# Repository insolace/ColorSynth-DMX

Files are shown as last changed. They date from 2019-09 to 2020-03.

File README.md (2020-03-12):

# ColorSynth-DMX<br>
163 DMX RGB pixels for a Burningman 2013 geodesic dome located at camp Morning Cookie<br>
Designed and assembled by Eric Bateman<br>
BMP to DMX mapping done in collaboration with Craig Dorety (http://craigdorety.com/)<br>

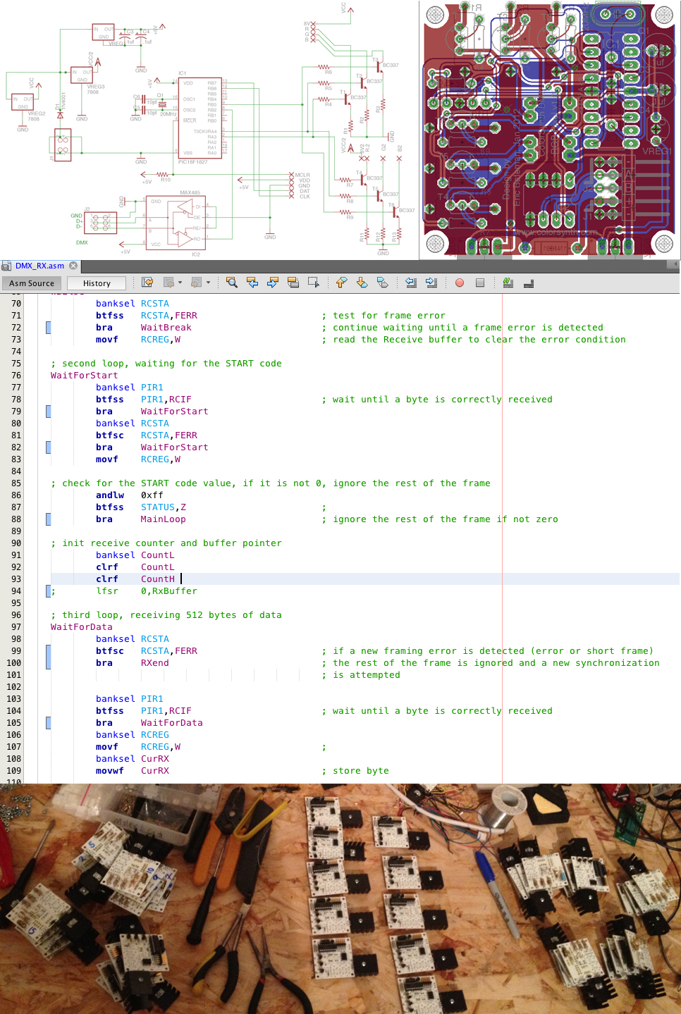
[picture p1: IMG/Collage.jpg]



ColorSynth DMX RGX pixels are three channel DMX fixtures.  Programmed in assembly, the channels are software defined.

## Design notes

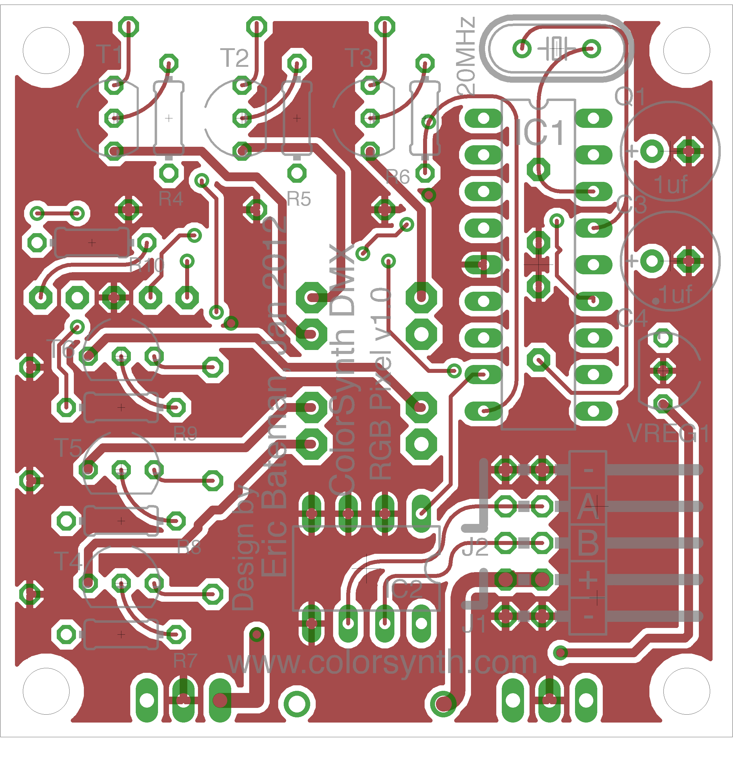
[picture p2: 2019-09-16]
PCB and Schematic/PCB export/DMX_RX_2RGB_TOP_BOTH.png

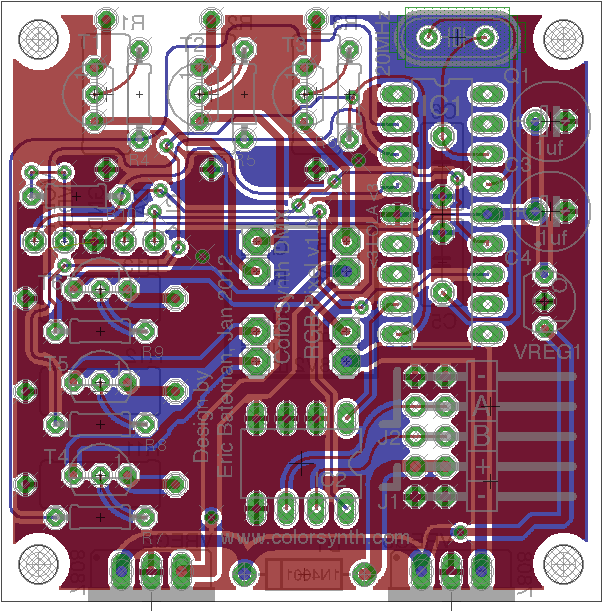
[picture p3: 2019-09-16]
PCB and Schematic/DMX RX PCB.png

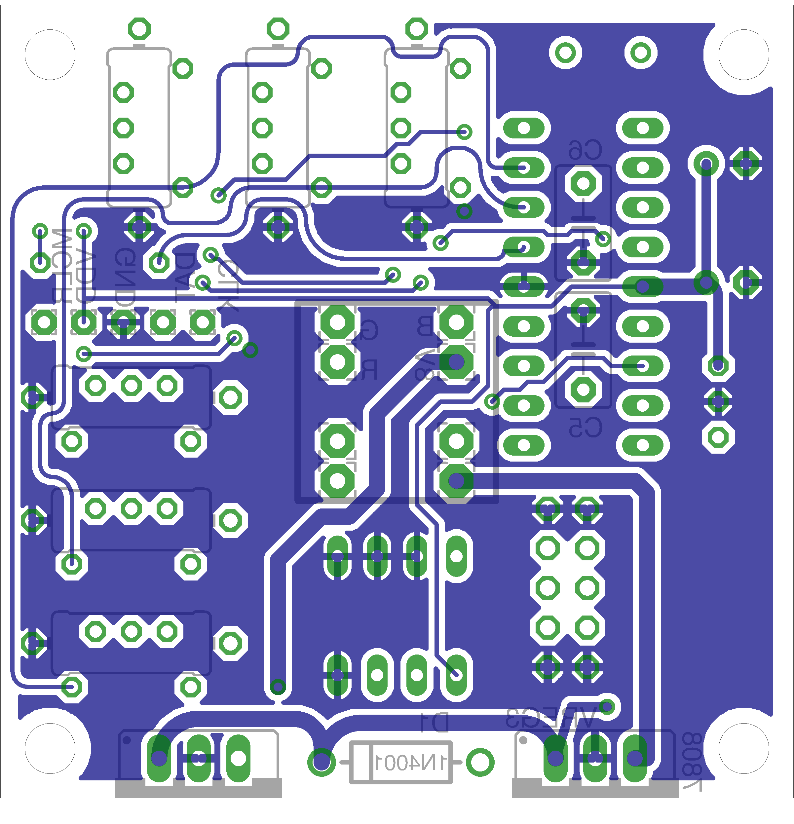
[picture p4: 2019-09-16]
PCB and Schematic/PCB export/DMX_RX_2RGB_BOT_BOTH.png

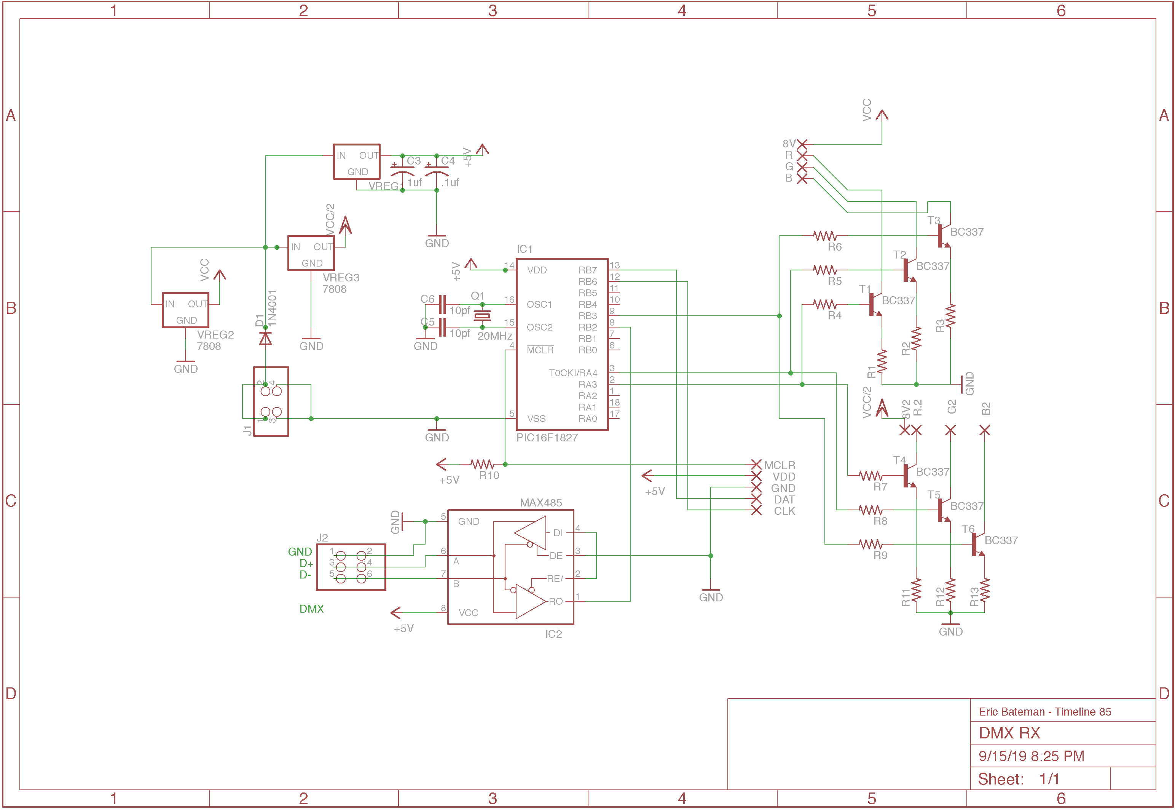
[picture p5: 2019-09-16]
PCB and Schematic/DMX RX Schematic.png

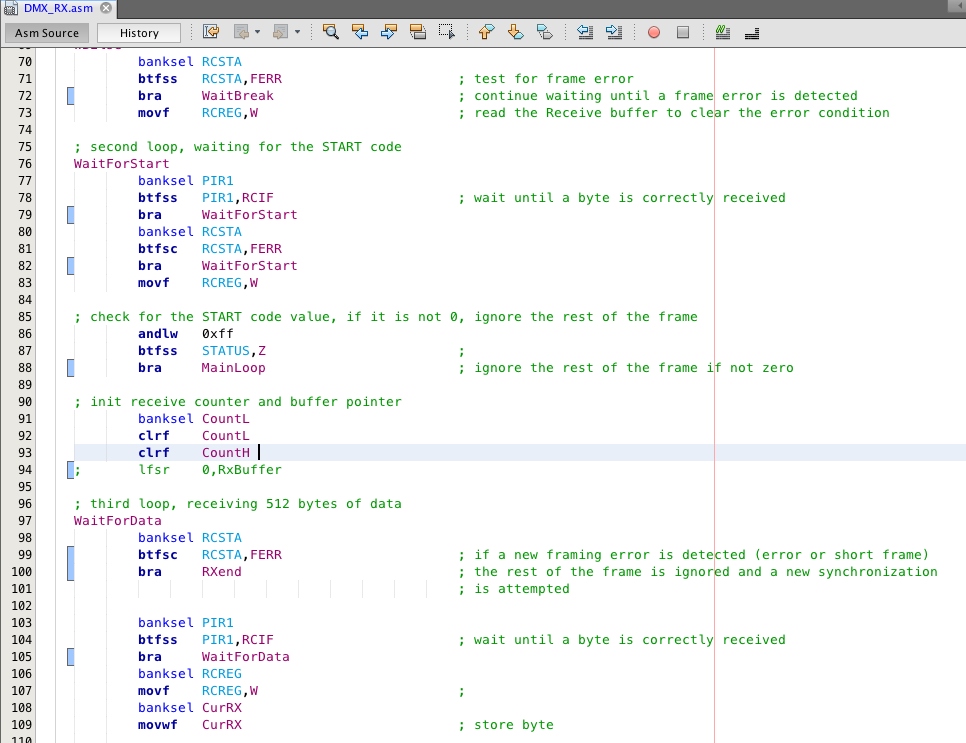
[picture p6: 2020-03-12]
IMG/DMX-ASM.png

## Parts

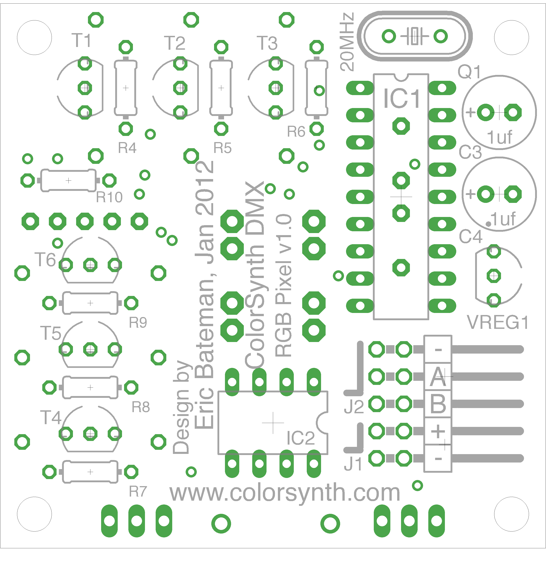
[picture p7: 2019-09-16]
PCB and Schematic/PCB export/DMX_RX_2RGB_TOP_PARTS.png

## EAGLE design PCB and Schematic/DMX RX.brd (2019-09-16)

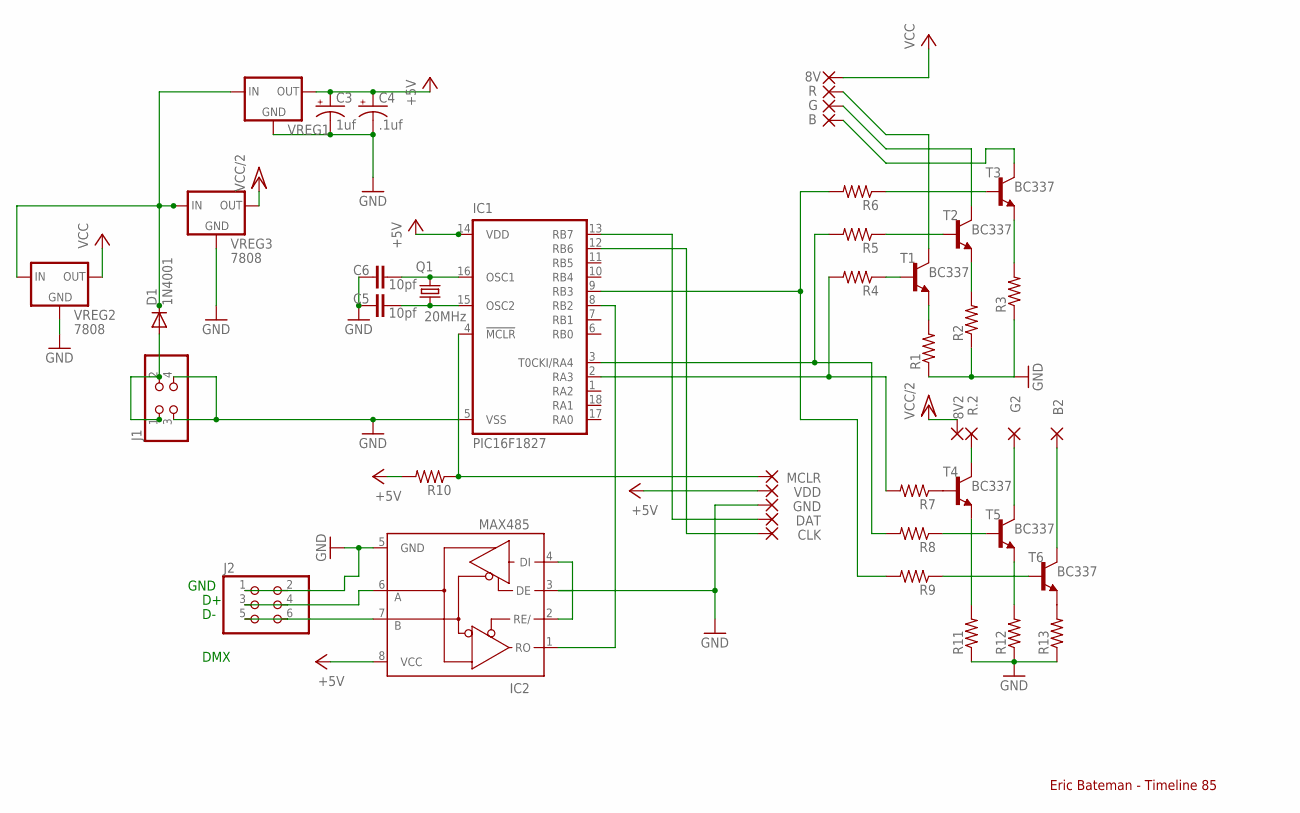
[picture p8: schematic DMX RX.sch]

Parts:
8V, 8V2: 2,15/1,0
B, B2: 2,15/1,0
C3: 1uf; E2,5-7
C4: .1uf; E2,5-7
C5, C6: 10pf; C5B3.5
CLK: 1,6/0,8
D1: 1N4001; DIODE-1N4001
DAT: 1,6/0,8
G, G2: 2,15/1,0
GND: 1,6/0,8
IC1: PIC16F1827; DIL18
IC2: MAX485; DIL08
J1: PINHD-2X2/90; 2X02/90
J2: PINHD-2X3/90; 2X03/90
MCLR: 1,6/0,8
Q1: 20MHz; HC49/S
R, R.2: 2,15/1,0
R1, R2, R3, R11, R12, R13: R-US_0411/12; 0411/12
R4, R5, R6, R7, R8, R9, R10: R-US_0204/7; 0204/7
T1, T2, T3, T4, T5, T6: BC337; TO92
VDD: 1,6/0,8
VREG1: 78LXX
VREG2, VREG3: 7808; 78XXS

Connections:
+5V: C3.+, C4.+, IC1.14 (VDD), IC2.8 (VCC), R10.2, VDD.1, VREG1.OUT
+12V: D1.C, VREG1.IN, VREG2.IN, VREG3.IN
A: IC2.6 (A), J2.3, J2.4
B: IC2.7 (B), J2.5, J2.6
CLK: CLK.1, IC1.12 (RB6)
DAT: DAT.1, IC1.13 (RB7)
DC-IN: D1.A, J1.1, J1.2
GND: C3.-, C4.-, C5.2, C6.2, GND.1, IC1.5 (VSS), IC2.2 (RE/), IC2.3 (DE), IC2.4 (DI), IC2.5 (GND), J1.3, J1.4, J2.1, J2.2, R1.1, R2.1, R3.1, R11.1, R12.1, R13.1, VREG1.GND, VREG2.GND, VREG3.GND
MCLR: IC1.4 (!MCLR), MCLR.1, R10.1
unnamed: R6.1, T3.2 (B)
unnamed: R3.2, T3.1 (E)
unnamed: R1.2, T1.1 (E)
unnamed: C6.1, IC1.16 (OSC1), Q1.1
unnamed: C5.1, IC1.15 (OSC2), Q1.2
unnamed: IC1.2 (RA3), R4.2, R7.2
unnamed: IC1.3 (T0CKI/RA4), R5.2, R8.2
unnamed: IC1.9 (RB3), R6.2, R9.2
unnamed: R5.1, T2.2 (B)
unnamed: R4.1, T1.2 (B)
unnamed: R.1, T1.3 (C)
unnamed: G.1, T2.3 (C)
unnamed: R2.2, T2.1 (E)
unnamed: R7.1, T4.2 (B)
unnamed: R13.2, T6.1 (E)
unnamed: R12.2, T5.1 (E)
unnamed: R11.2, T4.1 (E)
unnamed: R9.1, T6.2 (B)
unnamed: R8.1, T5.2 (B)
unnamed: G2.1, T5.3 (C)
unnamed: B2.1, T6.3 (C)
unnamed: R.2.1, T4.3 (C)
unnamed: B.1, T3.3 (C)
RX: IC1.8 (RB2), IC2.1 (RO)
VCC: 8V.1, VREG2.OUT
VCC/2: 8V2.1, VREG3.OUT

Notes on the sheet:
GND
DMX
Eric Bateman - Timeline 85

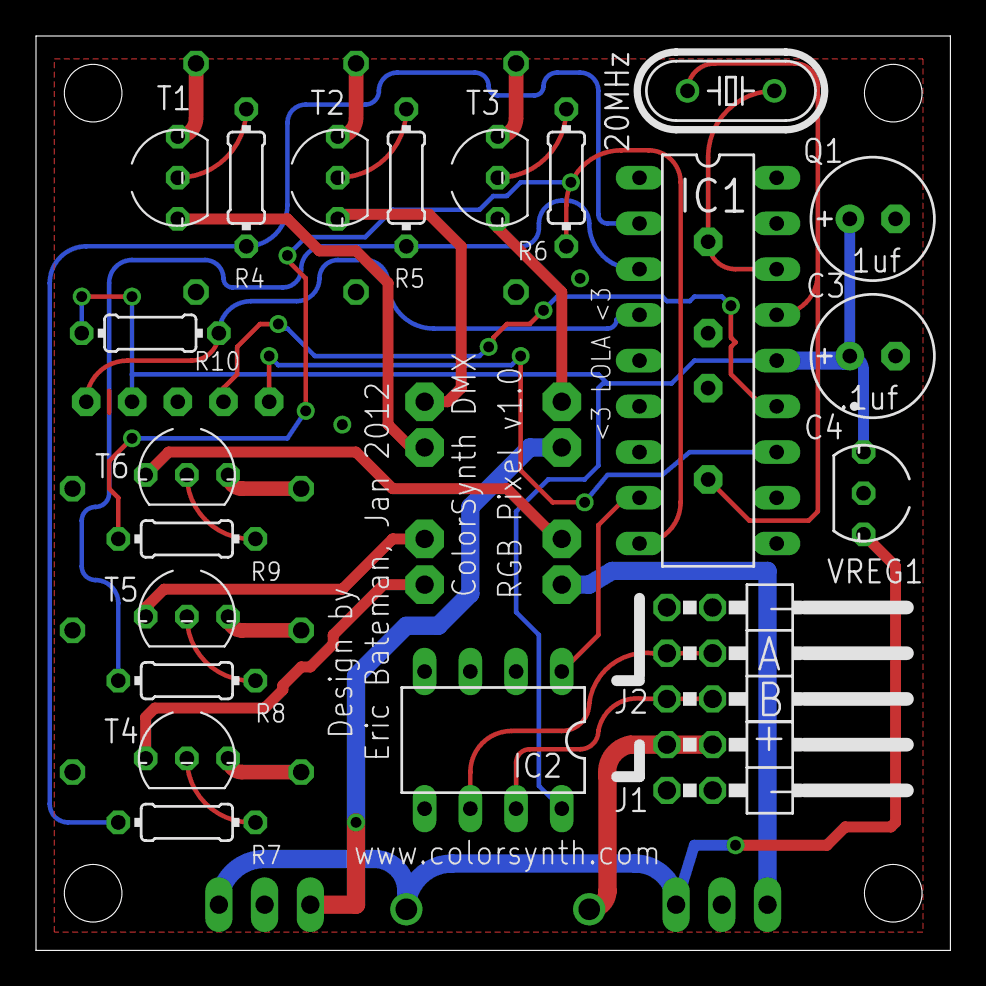
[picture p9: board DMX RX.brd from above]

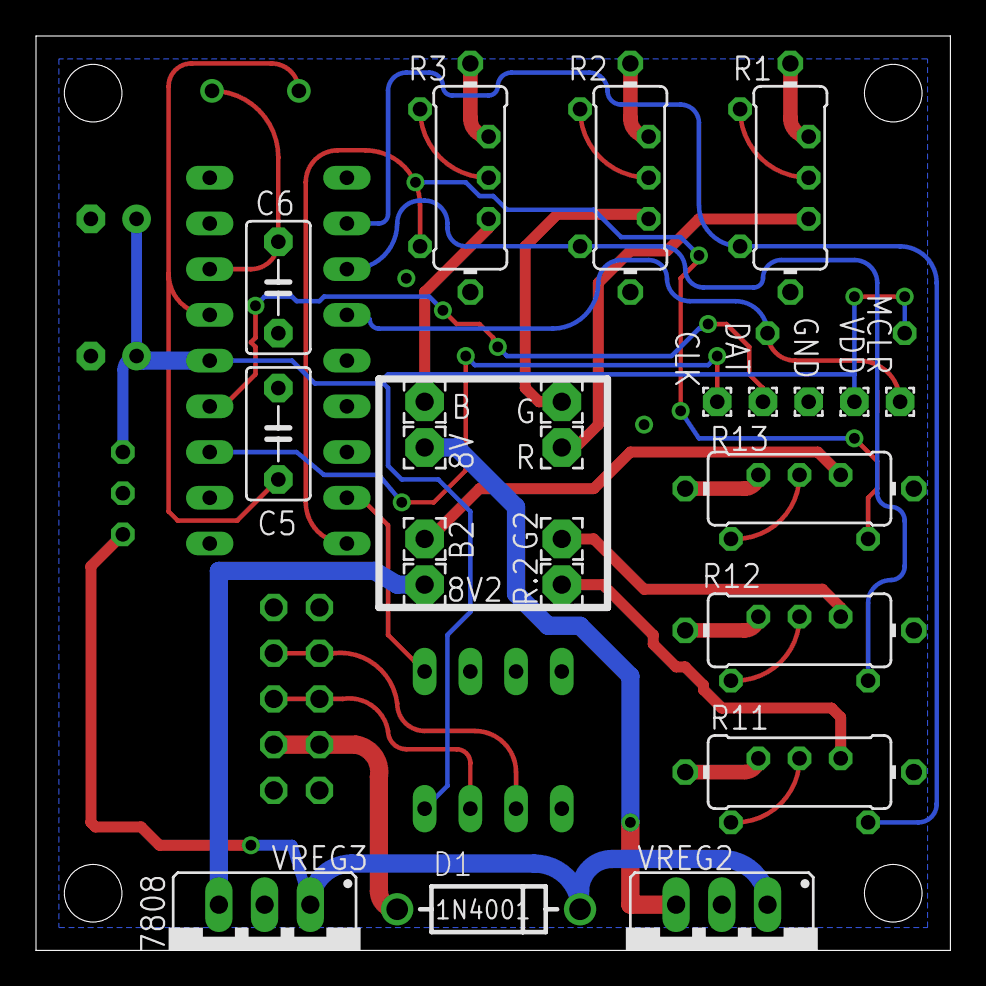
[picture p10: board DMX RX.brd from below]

Board: 2 copper layers, 50.8 x 50.8 mm, 45 parts (24 on the bottom side), 35 nets.

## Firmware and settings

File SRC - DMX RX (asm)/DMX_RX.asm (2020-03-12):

	list p=16f1827
	#include <P16F1827.inc>

;Configuration bits setup	 

	__CONFIG    _CONFIG1, _FCMEN_OFF & _IESO_OFF & _CLKOUTEN_OFF & _BOREN_OFF & _CPD_OFF & _CP_OFF & _MCLRE_OFF & _PWRTE_ON & _WDTE_OFF & _FOSC_HS
	__CONFIG    _CONFIG2, _LVP_OFF & _STVREN_OFF & _PLLEN_OFF & _WRT_OFF & _BORV_19

	 
; Constants 
#define CHANNEL .1            ; select the receiver slot/channel 

#define ArrayP1	0x20
#define ArrayP2 0x00+.3
 
; Variables 
	cblock h'20'
	    CountH                  ; 16-bit counter 
        CountL 
;	    RxBuffer: .512          ; 512 bytes buffer allocation 
		PWMR
		PWMG
		PWMB
		ColorOSC
		Color	 
		CurRX
		counta
		countb
		count1
	ENDC 
	 
;****************************************************************************** 
	ORG 	0x0 
 
Main 
	call	SetupSerial			;Setup Serial port and buffers 
 
MainLoop 
	 
; first loop, synchronizing with the transmitter 
WaitBreak 
;	call	InitBlink

	banksel PIR1
	btfss	PIR1,TXIF
	bra		SkipTX

	banksel	TXREG
	movlw	b'00000010'
	movwf	TXREG

SkipTX
	banksel	PIR1
	btfss	PIR1,RCIF           ; if a byte is received incorrectly 
	goto	WBElse				; skip

WBDisc
	banksel	RCREG
	movf	RCREG,W             ; if received correctly discard it 
	banksel	CurRX
	movwf	CurRX

	movlw	d'0'
	xorwf	CurRX
	btfsc	STATUS,Z	; if 0
	goto	WaitBreak	


WBElse
	banksel	RCSTA
	btfss	RCSTA,FERR			; test for frame error 
	bra	WaitBreak			; continue waiting until a frame error is detected 
	movf	RCREG,W				; read the Receive buffer to clear the error condition 
 
; second loop, waiting for the START code 
WaitForStart 
	banksel	PIR1
	btfss	PIR1,RCIF			; wait until a byte is correctly received 
	bra	WaitForStart 
	banksel	RCSTA
	btfsc	RCSTA,FERR 
	bra	WaitForStart 
	movf	RCREG,W	 
 
; check for the START code value, if it is not 0, ignore the rest of the frame 
	andlw   0xff 
	btfss	STATUS,Z			; 
	bra     MainLoop			; ignore the rest of the frame if not zero  
 
; init receive counter and buffer pointer         
	banksel	CountL
	clrf    CountL 
	clrf    CountH 
;       lfsr    0,RxBuffer 
 
; third loop, receiving 512 bytes of data 
WaitForData 
	banksel	RCSTA
	btfsc   RCSTA,FERR			; if a new framing error is detected (error or short frame) 
	bra     RXend				; the rest of the frame is ignored and a new synchronization 
						; is attempted 

	banksel	PIR1 
	btfss	PIR1,RCIF			; wait until a byte is correctly received 
	bra	WaitForData			 
	banksel	RCREG
	movf	RCREG,W				;  
	banksel	CurRX
	movwf	CurRX				; store byte	

	btfsc	CountH,0			; if > 255
	goto	DoneApply			; skip

	movlw	d'0'
	xorwf	CountL,w
	btfsc	STATUS,Z			; if equal then 
	bra		ApplyPWMR

	movlw	d'1'
	xorwf	CountL,w
	btfsc	STATUS,Z			; if equal then 
	bra		ApplyPWMG

	movlw	d'2'
	xorwf	CountL,w
	btfsc	STATUS,Z			; if equal then 
	bra		ApplyPWMB

	bra		DoneApply
 
ApplyPWMR 
	banksel	CurRX
	movf	CurRX,w				; collect byte
	banksel CCPR3L
	movwf	CCPR3L				; Move CH1 to PWMR
	bra		DoneApply

ApplyPWMG
	banksel	CurRX
	movf	CurRX,w				; collect byte
	banksel CCPR4L
	movwf	CCPR4L				; Move CH2 to PWMG
	bra		DoneApply

ApplyPWMB
	banksel	CurRX
	movf	CurRX,w				; collect byte
	banksel CCPR1L
	movwf	CCPR1L				; Move CH3 to PWMB
	
DoneApply	
	banksel	CountL

;	movwf	POSTINC0			; move the received data to the buffer  
                                ; (auto-incrementing pointer) 
	incf	CountL,F            ; increment 16-bit counter 
	btfss	STATUS,C 
	bra		WaitForData 
	incf	CountH,F 
 
	btfss	CountH,1            ; check if 512 bytes of data received 
	bra		WaitForData 
 
 
;****************************************************************************** 
; when a complete frame is received  
; use the selected CHANNEL data to control the CCP2 module duty cycle  
 
RXend 
;	lfsr	0,RxBuffer          ; use indirect pointer 0 to address the receiver buffer 
;GetData 
;	movlw	LOW(CHANNEL)       ; add the offset for the select channel 
;	addwf	FSR0L,F 
;	movlw	HIGH(CHANNEL) 
;	addwfc	FSR0H,F 
 
;	movff	INDF0,CCPR2L        ; retrieve the data and assign MSB to control PWM2 
 
	bra		MainLoop	        ; return to main loop  
 
 
;****************************************************************************** 
; Setup Serial port and pins
SetupSerial 

; initialize oscillator
	banksel	OSCCON	

;			movlw	b'01111010'
;			movwf	OSCCON

			clrf	OSCCON			; use OSC from CONFIG1
;			clrf	OSCTUNE			; factory OSC setting
	banksel	CLKRCON
;			clrf	CLKRCON			; ref clock disabled
			
; set alternate pin configurations (16f1827)

	banksel APFCON0
			bsf		APFCON0,RXDTSEL		; RX to RB2

	banksel APFCON1
			bsf		APFCON1,TXCKSEL		; TXCKSEL (0=RB2, 1=RB5)

;---------------------------------------------------------------------------------
; initialize PORTA/PORTB
;---------------------------------------------------------------------------------

PORT_Init	
	banksel	PORTA
			clrf	PORTA
			clrf	PORTB
	banksel	LATA 					
			CLRF 	LATA 			; clear PORTA Data Latch
			CLRF 	LATB 			; clear PORTB Data Latch

	banksel	TRISA
 

; RA0 = AN0
; RA1 = unused
; RA2 = unused
; RA3 = PWM output CCP3, RED, SET the pin to disable output driver for PWM
; RA4 = PWM output CCP4, GREEN, SET the pin to disable output driver for PWM
; RA5 = unused
; RA6 = output, oscillator out pin 1
; RA7 = output, oscillator in pin 2

	banksel TRISA
;			16f1827
			movlw	b'00111111'
			movwf	TRISA

; RB0 = unused
; RB1 = unused
; RB2 = UART input, DMX RX
; RB3 = PWM output CCP1, BLUE, SET the pin to disable output driver for PWM
; RB4 = Set as INPUT to transmit.  Output pulled low creates break signal. 
; RB5 = UART output, DMX TX
; RB6 = unused
; RB7 = unused

;			16f1827
			movlw 	b'11011111'
			movwf	TRISB
 
; Setup EUSART 

UART_Init				

	banksel	TXSTA					; also RCSTA, BAUDCON, SPBRGx

			bsf		RCSTA,SPEN  	; doesn't matter, we're in asynch mode, but whatever

	bsf	RCSTA,RX9
	bsf	TXSTA,TX9
	bsf	TXSTA,TX9D

			bcf		TXSTA,SYNC		; asynchronus mode (bit 4)		
			bsf 	TXSTA,TXEN		; enable Transmit (bit 5)

			bsf		TXSTA,BRGH		; high speed baud rate (bit 2)
			bsf		BAUDCON,BRG16

			clrf	SPBRGH
			movlw	d'19'			; 12mhz osc w/ high brgh
			movwf	SPBRGL			; init BRG 31250 bauds

			bcf		RCSTA,CREN  	; clear CREN, reset RX
			bsf		RCSTA,CREN  	; continuous receive enabled, restart RX


; ********************************************************************

;	banksel TXSTA

;	bsf		BAUDCON,BRG16	; select EUART 16-bit Asynchrnounou mode operation 
 
;	movlw	.19			    ; init baud rate generator for 250k baud (assume Fosc=20MHz) 
;	movwf	SPBRGL		 
;	clrf	SPBRGH
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

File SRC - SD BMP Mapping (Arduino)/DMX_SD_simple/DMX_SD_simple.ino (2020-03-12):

#include <SD.h>                                                  //calls the SD.h library
#include <DmxSimple.h>

int a, b, c, i, j;
int rawin;

#define STRIP_LENGTH 61//96 LEDs on this strip and how many pixels WIDE the photoshop file is
#define ARRAY_LENGTH 18111 // this is how many lines in the photoshop file


File myFile;                           //declares the public name of the file to open on the SD card

void setup() {
  pinMode(10, OUTPUT);  

  DmxSimple.usePin(5);
  DmxSimple.maxChannel(7);
  
//  Serial.begin(9600);
  if (!SD.begin(10)) {
//    Serial.println("initialization failed!");         //extra serial.print stuff that i only need for debugging
    return;
  }
}


void loop() {

  myFile = SD.open("rgb61x14.raw");
  if (myFile) {
 //     Serial.write("hello");
    for(j = 0; j<ARRAY_LENGTH; j++){                          
      for(i = 0 ; i < (STRIP_LENGTH*3) ; i++){
 
        rawin = myFile.read();
        DmxSimple.write(i+1, rawin);
//        Serial.write(i + ", " + rawin); 
      delay(5);        
      }

   }
    myFile.close();
  } 
  
}

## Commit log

2019-09-16 Source and PCB upload
    Initial upload
    [DMX RX.brd, DMX RX.sch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]
2020-03-12 Add Arduino SD sketch
